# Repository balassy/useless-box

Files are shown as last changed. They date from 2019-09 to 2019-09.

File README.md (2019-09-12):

# Smart Useless Box with ESP8266 and Gesture Sensor

A useless box made smarter with an ESP8266 microcontroller on a Wemos D1 Mini board and an APDS-9960 proximity sensor to give more funny responses.

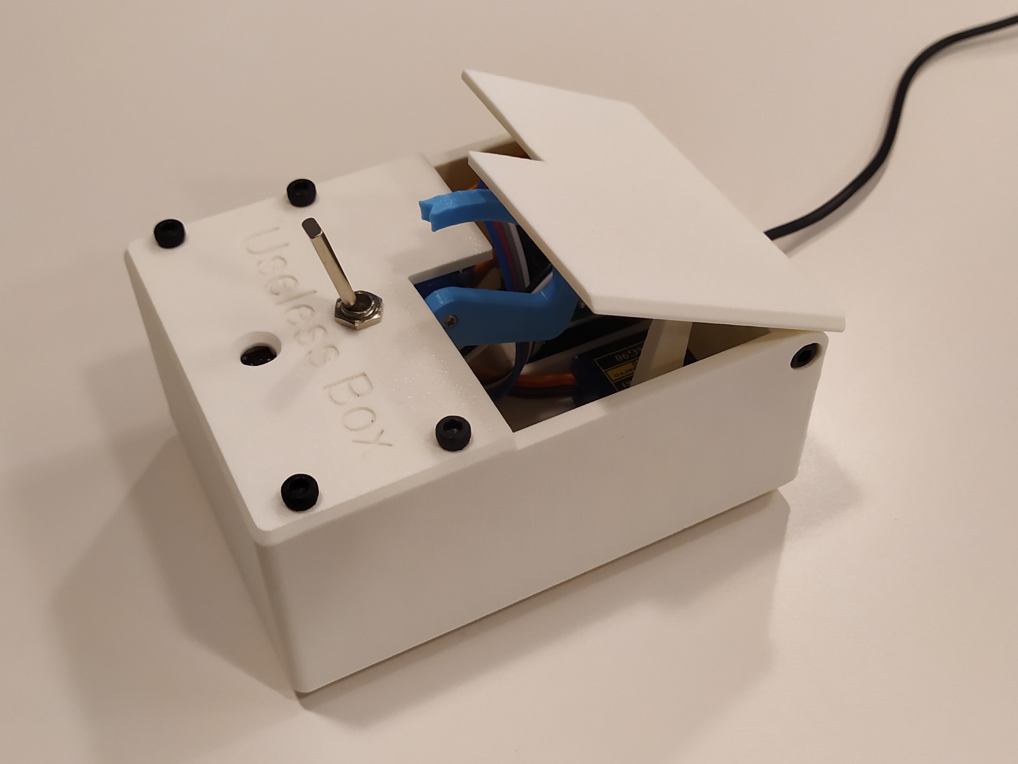
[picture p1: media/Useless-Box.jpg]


## YAUB (Yet Another Useless Box)?

Useless machines are not new, there are many versions available. You can create a simple one using a lever switch, however that will react always the same way. Using a programmable microcontroller you can create **funny, unexpected responses**, and by adding a proximity sensor you can surprise the user with **actions before she would even turn on the switch**!

This is a programmable useless box, so you have the option to implement **additional reactions** when you want to to further improve this funny little toy. What's more the used controller board has WiFi connectivity, so you can **connect it to other online services** (e.g. IFTTT) or **smart assistants** (Alexa, Cortana etc.).

## Smart Useless Box in Action

Click the image below to see this box in action:

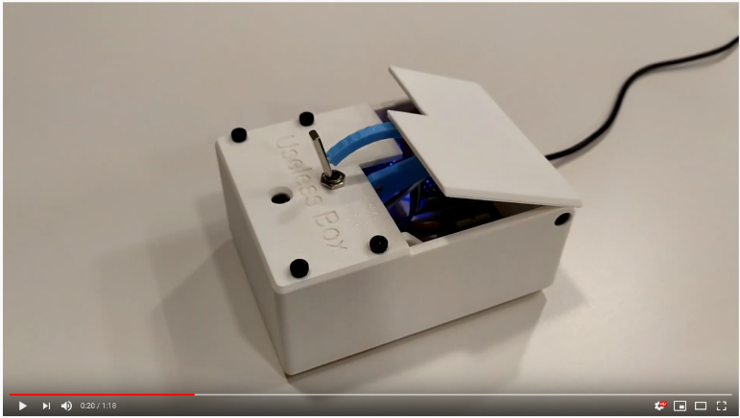
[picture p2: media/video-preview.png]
Smart Useless Box in Action (http://www.youtube.com/watch?v=x0kGetj1nt8 "Smart Useless Box in Action")


## Hardware

The following hardware components are required to build this project:

- 1 × [Wemos D1 Mini board](https://wiki.wemos.cc/products:d1:d1_mini)
- 1 × [APDS-9960 RGB, gesture and proximity sensor](https://www.sparkfun.com/products/12787) - there are multiple versions of this board, use one that follows the pinout of the SparkFun module to simplify wiring. I used [this](https://www.aliexpress.com/item/32768898229.html) cheap one from AliExpress.
- 2 × [SG90 servo motors](https://components101.com/servo-motor-basics-pinout-datasheet)
- 1 × Switch - you have to test this to ensure it flips easily and the servo is strong enough to flip it, so I bought mine in the nearest electronics hardware store.
- 1 × 1kΩ resistance
- Male pin headers:
  - 1 × 1x2 for the switch
  - 2 × 1x3 for the servo motors
  - 1 × 1x5 for the sensor
- Prototype board or PCB - to create a shield for the Wemos D1 Mini.
- Pin headers - to connect the shield to the Wemos D1 Mini.
- Dupont cables or wires with connectors.
- BluTack - to mount the wires and the controller board.
- M3 screws - to mount the lids.

## Wiring

The wiring is designed to create a custom shield for the Wemos D1 Mini ESP8266 microcontroller-based board, instead of soldering the cables directly to the board. In this way you can easily assemble the parts or even reuse them in the future.

### Schematics

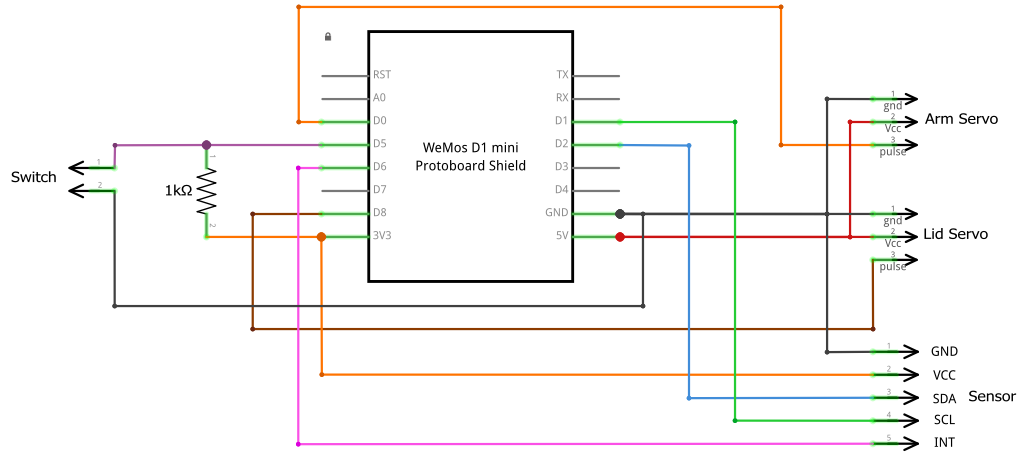
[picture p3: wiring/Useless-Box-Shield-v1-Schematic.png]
Schematic


### PCB

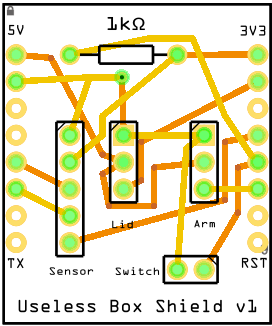
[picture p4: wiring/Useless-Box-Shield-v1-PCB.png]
PCB


The PCB was designed with [Fritzing](https://fritzing.org), and you can [download the source file](./wiring/Useless-Box-Shield-v1.fzz) to further customize it to your needs.

You can also [download the Gerber files](./wiring/Useless-Box-Shield-v1-PCB-Gerber.zip) which you can use to order the PCB from your preferred PCB manufacturer. (Note: I've created my prototype manually then documented it in Fritzing, so I have not tested this PCB yet.)

## Software

The source code in this repo is created with [Visual Studio Code](https://code.visualstudio.com) using the [Arduino plugin from Microsoft](https://marketplace.visualstudio.com/items?itemName=vsciot-vscode.vscode-arduino), but it should work with the [Arduino IDE](https://www.arduino.cc/en/main/software) as well.

The code in this repository is preconfigured with the pin layout shown in the wiring diagram above, but if you decide to connect the parts to different pins, you have to update the values in the `config.h` file.

After finalizing the pin configuration (or using the default one) just upload the code to the Wemos D1 Mini board.

The responses of the box are implemented in the `useless-box.ino` file, and the `run()` function is responsible for selecting and executing the reaction to a flip of the switch or to a signal from the sensor. Feel free to add new logic or remove any existing reaction you don't like in this function.

## The Box

I designed a custom box for this project which can be 3D printed or even further customized. You can download the model from [Thingiverse](https://www.thingiverse.com/thing:3856965) or [MyMiniFactory](https://www.myminifactory.com/object/3d-print-100944).

Happy Printing! :)

## About the author

This project is maintained by [György Balássy](https://linkedin.com/in/balassy).

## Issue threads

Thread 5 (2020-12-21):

Proximity value only between 0 and 4

EagleeyeKai, 2020-12-21:
Hi,
I used exactly the components listed here and wired everything as described. However I had to use Arduino IDE to flash my Wemos D1 Module. After flashing the console gives me Proximity Values between 0 and 4 randomly. It does not matter whether something is close or far from the sensor.

Anybody else has this behavior?

Kind regards

EagleeyeKai, 2020-12-21:
I found the issue. I needed to put a solder jumper ("PS") on my ADPS-Module.

Closed 2020-12-21.

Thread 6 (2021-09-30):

not working with esp8266

shrynshjn, 2021-09-30:
I tried using this with ESP8266, but initialization of the module fails.
Any ideas why?
Tell me if you do need any details to help debug it.
Or if you were able to use the sensor with an esp8266 could you share the details, that would be a huge help.
Thanks

Lyriss, 2022-05-31:
hi did u solve the problem?
i have the same issue

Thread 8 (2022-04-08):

Question about File format?

Devilcow, 2022-04-08:
Hello, I am waiting on my sensor board to arrive in order to finish building this. I just wanted to
1) Thank you! This is an awesome project! I had wanted to do one along these lines for sometime! I am planning on trying to add a speaker, and mp3 module to play random taunts and insults at the player LOL!
2) I was curious, what program is the PCB-Gerber.zip file made for? it looks like it's for manufacturing the PCB. In the past I had a version of Eagle that I did that from, but recently got Fritzing, so that is my new go to. I have always used the process of thermal transfer from laser print to the copper, then etched it with some home brew CuCl2. However I am considering trying to make my own tool mount for my 3d printer to make it a miniature 2D CNC. If these files are for some opensource or free milling app that would be really good to know!

Anyhow thanks again!
Cheers!

Devilcow, 2022-04-12:
LOL Nevermind, I realized it was in the documentation.

Closed 2022-04-12.

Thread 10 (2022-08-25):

Megépítettem, de nem működik

mmrobbie, 2022-08-25:
Szia!

Megépítettem, de nem működik. Induláskoz megzizzennek a szervók, és ennyi. Az arduino soros monitorban ilyenek vannak:
"⸮⸮⸮⸮⸮⸮⸮⸮⸮⸮⸮⸮⸮⸮⸮⸮⸮⸮⸮⸮⸮⸮⸮⸮⸮⸮⸮⸮⸮⸮⸮⸮⸮⸮⸮⸮⸮⸮⸮⸮⸮⸮⸮⸮⸮⸮⸮⸮⸮⸮⸮⸮⸮⸮⸮⸮⸮⸮⸮⸮⸮⸮⸮⸮⸮⸮⸮⸮⸮⸮⸮⸮⸮⸮⸮⸮⸮⸮⸮⸮⸮⸮⸮⸮⸮⸮⸮⸮⸮⸮⸮⸮⸮⸮⸮⸮⸮⸮⸮⸮⸮⸮⸮⸮⸮⸮⸮⸮⸮⸮⸮⸮⸮⸮⸮⸮⸮⸮⸮⸮⸮⸮⸮⸮⸮⸮⸮⸮⸮⸮⸮⸮⸮⸮⸮⸮⸮⸮⸮⸮⸮⸮⸮⸮⸮⸮⸮⸮⸮⸮⸮⸮⸮⸮⸮⸮⸮⸮⸮⸮⸮⸮⸮⸮⸮⸮⸮⸮⸮⸮⸮⸮⸮⸮⸮⸮⸮⸮⸮⸮⸮⸮⸮⸮⸮⸮⸮⸮⸮⸮⸮⸮⸮⸮⸮⸮⸮⸮⸮⸮⸮⸮⸮⸮⸮⸮⸮⸮⸮⸮⸮⸮⸮⸮⸮⸮⸮⸮⸮⸮⸮⸮⸮⸮⸮⸮⸮⸮⸮⸮ ⸮⸮⸮⸮⸮⸮⸮⸮⸮⸮⸮⸮⸮⸮⸮⸮<⸮<⸮⸮⸮⸮⸮⸮⸮⸮<⸮⸮⸮⸮"

Segíts kérlek! Mit rontok el?

Üdv:
mmrobbie
r@wsx.hu

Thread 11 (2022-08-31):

Switch servo not works

TillMoss, 2022-08-31:
I have made this Useless-box but switch servo rotate only 45 degrees. If in config.h I change 145 with other value servo rotate always 45degrees

Fullmetal11, 2022-10-14:
Same problem for me. Did you solve it?
Servo rotate max 90 degrees if i change 145 to 180 in config.h

chips32, 2022-11-10:
I have the same problem.  I am not an expert but I think it is do with the pulse width (in milliseconds) that is used for the servos.
I created a script to move the servo and found that I had to use the following for a full 180 movement.
void setup() {
  myservo.attach(0, 500, 2500);
0=pin, 500=min pulse width, 2500=max pulse width
Now I just have to figure out how to do it with the code supplied.
Any ideas?

Fullmetal11, 2022-11-11:
Unfortunately I don't know the programming language that well, however I have other sketches that move the same servo 180 degrees so I agree with you that it is definitely a code configuration problem, not an hardware problem.

Doka85, 2023-01-09:
Sorry for my bad english, but i think, the follow steps will solve your Problem @TillMoss and @Fullmetal11

you have to calibrate the min and max pulsewidth in servo.h, located in \AppData\Local\Arduino15\packages\esp8266\hardware\esp8266\3.0.1\libraries\Servo\src\

`#define DEFAULT_MIN_PULSE_WIDTH      1000 // uncalibrated default, the shortest duty cycle sent to a servo
#define DEFAULT_MAX_PULSE_WIDTH      2000 // uncalibrated default, the longest duty cycle sent to a servo
#define DEFAULT_NEUTRAL_PULSE_WIDTH  1500 // default duty cycle when servo is attached`

in my case i have set to 500 and 2500, like  @chips32

Fullmetal11, 2023-01-10:
@Doka85 Thak you!!!

As you suggested, I change the value:

#define DEFAULT_MIN_PULSE_WIDTH      500 // uncalibrated default, the shortest duty cycle sent to a servo
#define DEFAULT_MAX_PULSE_WIDTH      2500 // uncalibrated default, the longest duty cycle sent to a servo

in the file servo.h located in \AppData\Local\Arduino15\packages\esp8266\hardware\esp8266\3.0.1\libraries\Servo\src\ and I solved the problem, now it work good!!!!!
So happy now!!! :-)

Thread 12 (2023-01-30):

Error when comiling in Arduino IDE

rstrich, 2023-01-30:
Have built and used your default pin layout, however get the following error when compiling using Arduino IDE, any suggestions?:-

C:\[DocRoot]\Arduino\useless-box\proximity-sensor.cpp: In member function 'uint8_t ProximitySensor::getProximity()':
C:\[DocRoot]\Arduino\useless-box\proximity-sensor.cpp:45:19: error: control reaches end of non-void function [-Werror=return-type]
   45 |     Serial.println(F("ProximitySensor: Reading proximity value FAILED!"));
      |     ~~~~~~~~~~~~~~^~~~~~~~~~~~~~~~~~~~~~~~~~~~~~~~~~~~~~~~~~~~~~~~~~~~~~~
cc1plus.exe: some warnings being treated as errors
Multiple libraries were found for "Servo.h"
  Used: C:\*****\AppData\Local\Arduino15\packages\esp8266\hardware\esp8266\3.1.1\libraries\Servo
  Not used: C:\*****\AppData\Local\Arduino15\libraries\Servo
exit status 1

Compilation error: control reaches end of non-void function [-Werror=return-type]

CableBasti, 2023-02-23:
hello rstich,

i have the same problem. Do you already have a solution?

ConradsenDK, 2023-03-08:
did ya find a solution?
seems i ran in the same issue

priest6479, 2023-05-02:
I found the solution on that forum..
https://forum.arduino.cc/t/probleme-beim-kompilieren-in-der-arduino-ide/1094051/2

in proximity-sensor.cpp

Add a new line between lines 46 and 47. It should look something like this...

      }
  return 0;
}

worked perfect for me

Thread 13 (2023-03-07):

failing when compiling ....

ConradsenDK, 2023-03-07:
C:\Users\jocon\OneDrive\Dokumenter\Arduino\useless-box\proximity-sensor.cpp: In member function 'uint8_t ProximitySensor::getProximity()':
C:\Users\jocon\OneDrive\Dokumenter\Arduino\useless-box\proximity-sensor.cpp:45:19: error: control reaches end of non-void function [-Werror=return-type]
   45 |     Serial.println(F("ProximitySensor: Reading proximity value FAILED!"));
      |     ~~~~~~~~~~~~~~^~~~~~~~~~~~~~~~~~~~~~~~~~~~~~~~~~~~~~~~~~~~~~~~~~~~~~~
cc1plus.exe: some warnings being treated as errors
Multiple libraries were found for "Servo.h"
  Used: C:\Users\jocon\AppData\Local\Arduino15\packages\esp8266\hardware\esp8266\3.1.1\libraries\Servo
  Not used: C:\Users\jocon\AppData\Local\Arduino15\libraries\Servo
exit status 1

Compilation error: control reaches end of non-void function [-Werror=return-type]

not sure what to do? any one can help
i only need the programing..  then i can test

priest6479, 2023-05-02:
I found the solution in this forum..
https://forum.arduino.cc/t/probleme-beim-kompilieren-in-der-arduino-ide/1094051/2

in proximity-sensor.cpp

Add a new line between lines 46 and 47. It should look something like this...

      }
  return 0;
}

worked fine for me after that

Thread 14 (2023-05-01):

Servos Moving Very slow

priest6479, 2023-05-01:
Everything seems to be working as expected but I have noticed my Servos are moving extremely slow.

Initially I have powered this from my laptop, now a standard USB phone charger, no change

I am running SG90 Servos as well

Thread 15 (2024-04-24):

Unable to run

DuffyManCZ, 2024-04-24:
I am trying to get this work but without success so far.
I have encountered two issues with the code
1. When opening the sketch the file needs to be renamed to have the same name as the folder, which in case of downloading from GitHub has -master at the end.
2. Error while compiling which has been already solved [here](https://github.com/balassy/useless-box/issues/13#issue-1613533865)

But now, when I upload the code to the ESP, absolutely nothing happens. No matter what I do, nothing. I am sure the wiring is correct.

Any ideas, please?
Thanks!

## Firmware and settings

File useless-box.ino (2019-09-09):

// Platform libraries.
#include <Arduino.h>  // To add IntelliSense for platform constants.

// Third-party libraries.

// My classes.
#include "speed-servo.h"
#include "status-led.h"
#include "proximity-sensor.h"

#include "config.h"  // To store configuration and secrets.

SpeedServo lidServo;
SpeedServo switchServo;
StatusLed led;
ProximitySensor sensor;

int lastSwitchState = 0;
long playCount = 0;
bool isLidOpen = false;
bool monitorSensor = false;

void setup() {
  initSerial();
  initServos();
  initLed();
  initSensor();
  pinMode(PIN_SWITCH, INPUT);

  Serial.printf("Application version: %s\n", APP_VERSION);
  Serial.println("Setup completed.");
}

void initSerial() {
  Serial.begin(115200);
  Serial.println();
  Serial.println("Initializing serial connection DONE.");
}

void initServos() {
  lidServo.attach(PIN_LID_SERVO);
  lidServo.moveNowTo(LID_START_POSITION);

  switchServo.attach(PIN_SWITCH_SERVO);
  switchServo.moveNowTo(SWITCH_START_POSITION);
}

void initLed() {
  led.setPin(LED_BUILTIN);
  led.turnOff();
}

void initSensor() {
  sensor.attach(PIN_SENSOR_SDA, PIN_SENSOR_SCL, SENSOR_TRIGGER_THRESHOLD);
}

void loop() {
  int switchState = digitalRead(PIN_SWITCH);
  boolean isSwitchTurnedOn = (switchState != lastSwitchState) && (switchState == LOW);

  if (isSwitchTurnedOn) {
    led.turnOn();
    run();
    isLidOpen = false;
    led.turnOff();
  } else {
    // Check the proximity sensor.
    if (sensor.isInRange()) {
      if (!isLidOpen && monitorSensor) {
        openLidFast();
        isLidOpen = true;
      }
    } else {
      if (isLidOpen) {
        closeLidFast();
        isLidOpen = false;
      }
    }
  }

  lastSwitchState = switchState;

  // Wait 250 ms before next reading (required for the sensor).
  delay(250);
}

void run() {
  switch (playCount % 10) {
    case 0:
    case 1:
      runSlow();
      break;
    case 2:
      runWaitThenFast();
      break;
    case 3:
      runFast();
      break;
    case 4:
      runFastThenClap();
      monitorSensor = true;
      break;
    case 5:
      runOpenCloseThenFast();
      monitorSensor = false;
      break;
    case 6:
      runPeekThenFast();
      break;
    case 7:
      runFastWithDelay();
      monitorSensor = true;
      break;
    case 8:
      runClap();
      monitorSensor = false;
      break;
    case 9:
      runHalf();
      break;
    default:
      break;
  }

  playCount++;
}

void runSlow() {
  openLidSlow();
  flipSwitchSlow();
  closeLidSlow();
}

void runWaitThenFast() {
  delay(5000);
  flipSwitchFast();
}

void runFast() {
  flipSwitchFast();
}

void runFastThenClap() {
  flipSwitchFast();
  clapLid();
}

void runOpenCloseThenFast() {
  openLidSlow();
  delay(2000);
  closeLidSlow();
  delay(2000);
  flipSwitchFast();
}

void runPeekThenFast() {
  switchServo.moveSlowTo(SWITCH_HALF_POSITION);
  delay(3000);
  switchServo.moveFastTo(SWITCH_START_POSITION);
  delay(3000);
  flipSwitchFast();
}

void runFastWithDelay() {
  openLidSlow();
  delay(4000);
  flipSwitchFast();
  closeLidFast();
}

void runClap() {
  clapLid();
  clapLid();
  clapLid();
  clapLid();
  openLidFast();
  flipSwitchFast();
  closeLidFast();
}

void runHalf() {
  switchServo.moveSlowTo(SWITCH_HALF_POSITION);
  delay(3000);
  switchServo.moveFastTo(SWITCH_END_POSITION);
  switchServo.moveFastTo(SWITCH_START_POSITION);
}

void openLidSlow() {
  lidServo.moveSlowTo(LID_END_POSITION);
}

void openLidFast() {
  lidServo.moveFastTo(LID_END_POSITION);
}

void closeLidSlow() {
  lidServo.moveSlowTo(LID_START_POSITION);
}

void closeLidFast() {
  lidServo.moveFastTo(LID_START_POSITION);
}

void clapLid() {
  openLidFast();
  closeLidFast();
}

void flipSwitchSlow() {
  switchServo.moveSlowTo(SWITCH_END_POSITION);
  switchServo.moveSlowTo(SWITCH_START_POSITION);
}

void flipSwitchFast() {
  switchServo.moveFastTo(SWITCH_END_POSITION);
  switchServo.moveFastTo(SWITCH_START_POSITION);
}

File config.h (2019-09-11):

const char* APP_VERSION = "0.0.1";

#ifndef LED_BUILTIN
#define LED_BUILTIN D4
#endif

const int PIN_LID_SERVO = D8;     // The GPIO number of the pin where the lid opener servo is connected.
const int PIN_SWITCH_SERVO = D0;  // The GPIO number of the pin where the switch manipulator servo is connected.
const int PIN_SWITCH = D5;        // The GPIO number of the pin where the switch is connected.
const int PIN_SENSOR_SDA = D2;    // The GPIO number of the pin where the SDA pin of the APDS-9660 sensor is connected.
const int PIN_SENSOR_SCL = D1;    // The GPIO number of the pin where the SCL pin of the APDS-9660 sensor is connected.
const uint8_t SENSOR_TRIGGER_THRESHOLD = 100;  // The proximity value level that triggers a lid opening. (lower=brighter, higher=darker)

const int LID_START_POSITION = 90;
const int LID_END_POSITION = 40;
const int SWITCH_START_POSITION = 0;
const int SWITCH_END_POSITION = 145;
const int SWITCH_HALF_POSITION = 90;

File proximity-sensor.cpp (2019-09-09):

#include "proximity-sensor.h"

void ProximitySensor::attach(uint8_t sdaPin, uint8_t sclPin, uint8_t rangeThreshold) {
  Serial.println(F("ProximitySensor: Initializing..."));

  _sensor = SparkFun_APDS9960();

  Serial.println(F("ProximitySensor: Starting I2C..."));
  Wire.begin(sdaPin, sclPin);
  Serial.println(F("ProximitySensor: Starting I2C...DONE"));

  Serial.println(F("ProximitySensor: Configuring I2C and initial values..."));
  if (_sensor.init()) {
    Serial.println(F("ProximitySensor: Configuring I2C and initial values...DONE"));
  } else {
    Serial.println(F("ProximitySensor: Configuring I2C and initial values...FAILED!"));
  }

  Serial.println(F("ProximitySensor: Adjusting the sensor gain..."));
  if (_sensor.setProximityGain(PGAIN_2X)) {
    Serial.println(F("ProximitySensor: Adjusting the sensor gain...DONE"));
  } else {
    Serial.println(F("ProximitySensor: Adjusting the sensor gain...FAILED!"));
  }

  Serial.println(F("ProximitySensor: Starting the sensor..."));
  bool enableInterrupts = false;
  if (_sensor.enableProximitySensor(enableInterrupts)) {
    Serial.println(F("ProximitySensor: Starting the sensor...DONE"));
  } else {
    Serial.println(F("ProximitySensor: Starting the sensor...FAILED!"));
  }

  _rangeThreshold = rangeThreshold;

  Serial.println(F("ProximitySensor: Initializing...DONE"));
}

uint8_t ProximitySensor::getProximity() {
  if ( _sensor.readProximity(_lastProximityValue) ) {
    Serial.print(F("ProximitySensor: Proximity value: "));
    Serial.println(_lastProximityValue);
    return _lastProximityValue;
  } else {
    Serial.println(F("ProximitySensor: Reading proximity value FAILED!"));
  }
}

bool ProximitySensor::isInRange() {
  uint8_t currentProximityValue = getProximity();
  return currentProximityValue > _rangeThreshold;
}

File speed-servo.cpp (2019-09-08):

#include "speed-servo.h"

const int SLOW_MOVE_DELAY = 15;
const int Fast_MOVE_DELAY = 2;

void SpeedServo::attach(uint8_t pin) {
  _servo.attach(pin);
}

// Valid position: 0-180.
void SpeedServo::moveNowTo(int newPosition) {
  _lastPosition = newPosition;
  _servo.write(newPosition);
}

// Valid position: 0-180.
void SpeedServo::moveFastTo(int newPosition) {
  _moveTo(newPosition, Fast_MOVE_DELAY);
}

// Valid position: 0-180.
void SpeedServo::moveSlowTo(int newPosition) {
  _moveTo(newPosition, SLOW_MOVE_DELAY);
}

// Valid position: 0-180.
void SpeedServo::_moveTo(int newPosition, unsigned long stepDelay) {
  if(newPosition > _lastPosition) {
    for (int pos = _lastPosition; pos <= newPosition; pos++) {
      _servo.write(pos);
      delay(stepDelay);
    }
  } else {
    for (int pos = _lastPosition; pos >= newPosition; pos--) {
      _servo.write(pos);
      delay(stepDelay);
    }
  }

  _lastPosition = newPosition;
}

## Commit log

2019-04-17 ADDED: First servo code.
2019-04-18 ADDED: Control two servo motors.
2019-04-18 ADDED: Led and switch controlled servos.
2019-04-18 ADDED: Open-flip-close sequence is executed when the switch is pressed.
    [useless-box.ino]
2019-04-18 REFACTORED: Renamed "button" to "switch".
2019-09-08 CHANGED: Switched to Wemos D1 Mini.
2019-09-08 FIXED: Slow servo rotation is also made in steps.
    [speed-servo.cpp]
2019-09-09 ADDED: Proximity sensor first iteration.
2019-09-09 REFACTORED: Sensor operation are moved to the ProximitySensor class.
2019-09-09 ADDED: Sensor logic is part of the run selection.
2019-09-10 ADDED: Wiring files.
    [Useless Box Shield v1.fzz]
2019-09-11 CHANGED: Added config.h directly, removed config.sample.h.
2019-09-11 ADDED: Wiring section to the README.
2019-09-11 FIXED: Removed whitespaces from the file names to display the images in the README.
    [Useless-Box-Shield-v1.fzz]
